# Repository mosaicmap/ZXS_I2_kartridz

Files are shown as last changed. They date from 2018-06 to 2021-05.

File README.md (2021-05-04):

# ZXS_I2_kartridz

Simple ROM cartridge for [Sinclair ZX Interface 2](https://en.wikipedia.org/wiki/ZX_Interface_2).

**This is basically updated Droy's [ZX Cart](http://trastero.speccy.org/cosas/droy/cartuchos/cartuchos_s.htm)**. My version contains an EEPROM chip **W27C512** instead of the 27\*128 or 27\*256. The main reason is that the W27C512 is more common and cheaper than 27\*128 and 27\*256 chips nowadays (Search for W27C512 on eBay...) W27C512 has also a bigger capacity. One cartridge can hold up to four 16 KiB ROM banks. Of course, only one ROM file can be active at one time.  

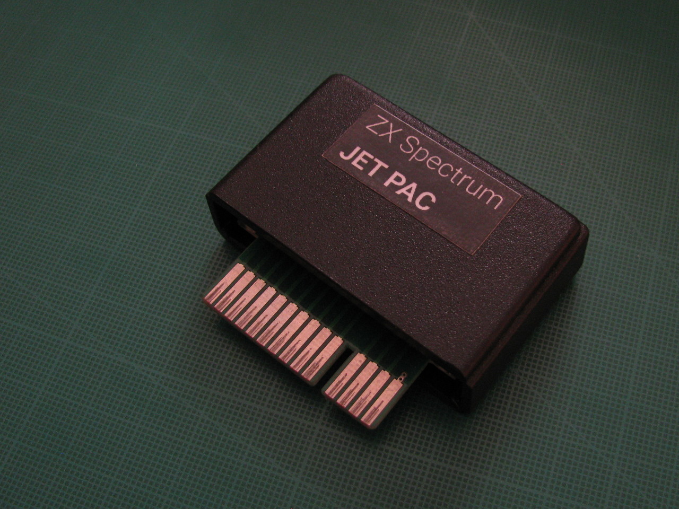
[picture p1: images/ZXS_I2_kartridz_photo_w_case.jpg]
photo_with_case


## Notes 

A HW programmer is required for uploading the ROM file to the EEPROM chip. For example, a relatively cheap universal programmer *MiniPro TL866CS* or *MiniPro TL866 II* from eBay is sufficient. Another option may be a homemade EEPROM programmer made of an Arduino; check for example [eeprom_programmer by StormTrooper](https://github.com/StormTrooper/eeprom_programmer) and similar projects.

To simplify ROMs upload it is possible concat four ROM files to a single file. Command under Linux/Unix: ``cat 1.rom 2.rom 3.rom 4.rom > myCompilation.rom``; under Windows/MS-DOS: ``copy /b 1.rom + 2.rom + 3.rom + 4.rom myCompilation.rom``

Jumpers A14 and A15 decide which 16 KiB ROM bank is active. (A14 and A15 are address pins of the W27C512, not A14 and A15 of the ZX Spectrum Edge connector)

This is only a simple ROM cartridge for 16 KiB ROMs. If you want a better cartridge, check for example sophisticated [Paul Farrow's ZXC4 cartridge](http://www.fruitcake.plus.com/Sinclair/Interface2/Cartridges/Interface2_RC_ZXC4.htm)

## EAGLE project

The project contains: schematic ``ZXS_I2_kartridz.sch`` and board ``ZXS_I2_kartridz.brd``. Also ``lbr/zxs_i2_rom_edge_connector.lbr`` is required.

It was created with a freeware version of Autodesk EAGLE.

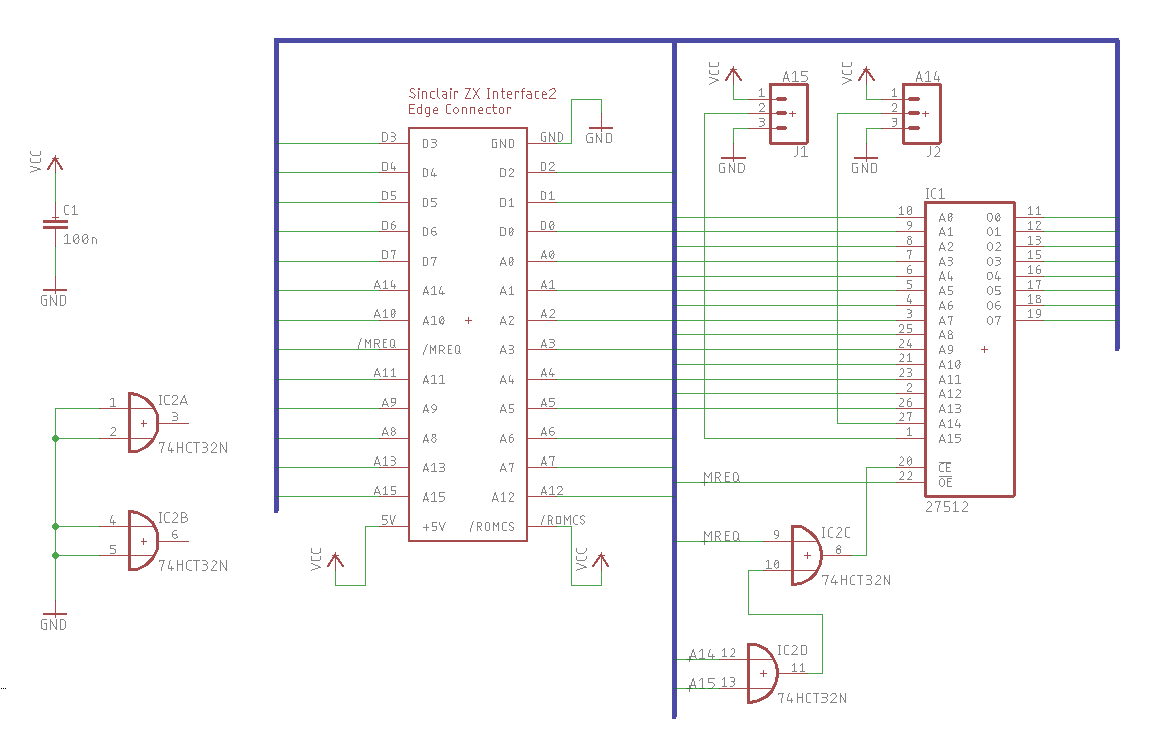
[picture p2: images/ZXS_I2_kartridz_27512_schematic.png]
screenshot-schematic


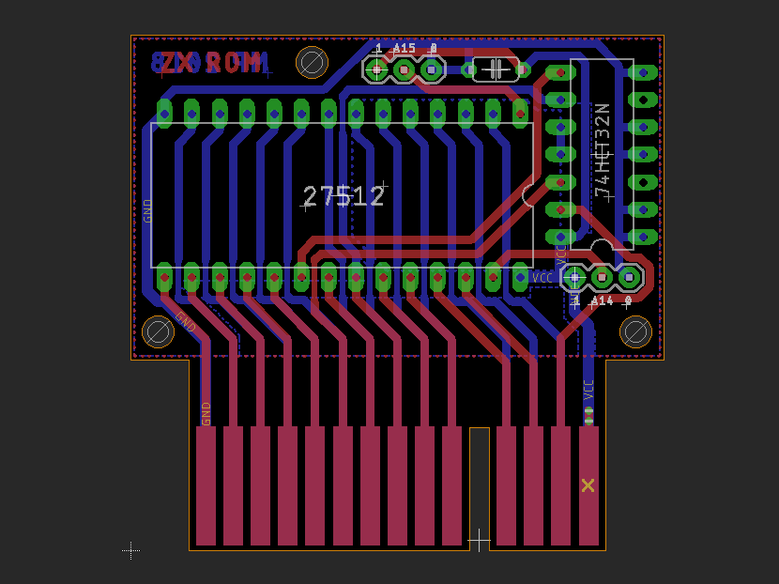
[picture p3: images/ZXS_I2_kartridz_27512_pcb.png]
screenshot-pcb


## ROMs

See nice [overview by Paul Farrow](http://www.fruitcake.plus.com/Sinclair/Interface2/Cartridges/Interface2_RC_Cartridges.htm)

### Officialy released games (1984)

Originaly was released only 10 games. Namely:

- Backgammon
- Cookie
- Chess
- Horace and the Spiders
- Hungry Horace
- Jetpac
- Planetoids
- PSSST
- Space Raiders
- Tranz Am

You can download all ROM files of these games as [archive carts.zip](http://trastero.speccy.org/cosas/droy/cartuchos/carts.zip)

### Unreleased prototypes (cancelled)

- Popeye
- Q*Bert
- Gyruss
- Star Wars - The Arcade Game
- Return of the Jedi - Death Star Battle
- Loco Motion
- Montezuma's Revenge

### Sinclair BASIC for ZX Spectrum (1982) 

### Alternative BASIC interpreters

- OpenSE BASIC (mirrors: [worldofspectrum](https://worldofspectrum.org/archive/software/utilities/opense-basic-andrew-s-owen), [spectrumcomputing](https://spectrumcomputing.co.uk/entry/27510/ZX-Spectrum/OpenSE_BASIC))
- Gosh Woderful BASIC by Geoff Wearmouth ([mirror](https://8bit.yarek.pl/upgrade/zx.roms/gw03.zip))
- [Busy Soft ROM](https://busy.speccy.cz/tvorba/zxromky.htm)
- [prettybasic](https://github.com/reclaimed/prettybasic)
- ...

### Diagnostics 

Very useful ROMs for testing hardware of the ZX Spectrum.

- [Retroleum Diag ROM](http://blog.retroleum.co.uk/smart.zip) 
- [ZX-Diagnostics ROM by Brendan Alford](https://github.com/brendanalford/zx-diagnostics/releases)

### Experimental games

- DeathStar (8 KiB) (See [on fruitcake.plus.com](http://www.fruitcake.plus.com/Sinclair/Interface2/Cartridges/Interface2_RC_New_3rdParty_DeathStar.htm))

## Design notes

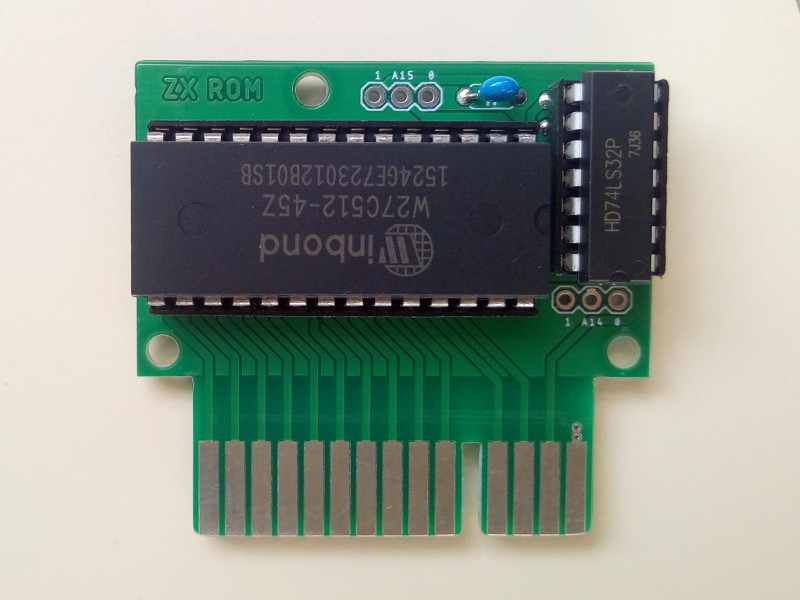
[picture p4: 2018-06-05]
images/ZXS_I2_kartridz_photo_no_jumpers.jpg

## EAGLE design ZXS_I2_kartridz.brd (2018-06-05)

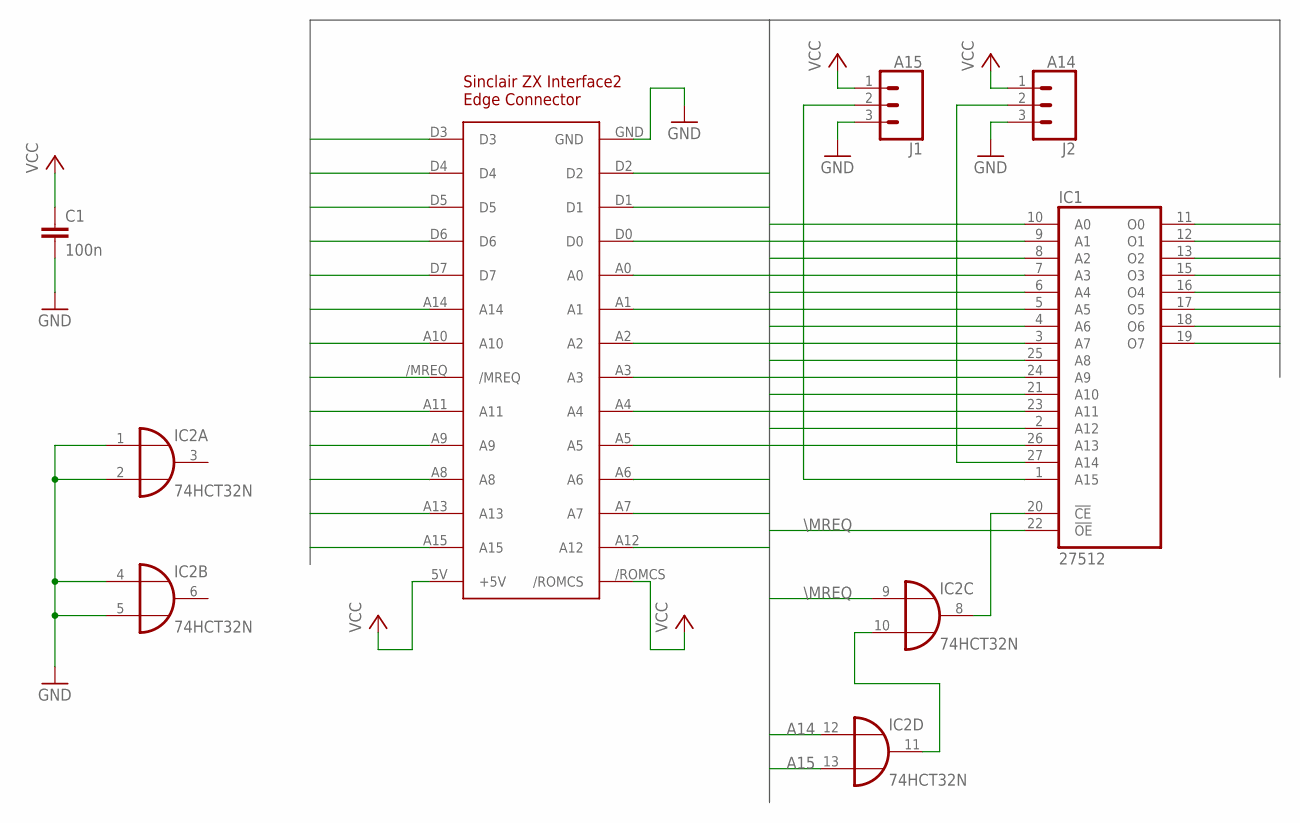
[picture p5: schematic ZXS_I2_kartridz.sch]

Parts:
C1: 100n; C050-024X044
IC1: 27512; DIL28
IC2: 74HCT32N; DIL14
J1: A15; 1X03
J2: A14; 1X03
U$1: ZX_I2_ROM_EDGE_CONNECTOR; ZX_I2_ROM_EDGE_CONNECTOR_V2

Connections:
A0: IC1.10 (A0), U$1.A0
A1: IC1.9 (A1), U$1.A1
A2: IC1.8 (A2), U$1.A2
A3: IC1.7 (A3), U$1.A3
A4: IC1.6 (A4), U$1.A4
A5: IC1.5 (A5), U$1.A5
A6: IC1.4 (A6), U$1.A6
A7: IC1.3 (A7), U$1.A7
A8: IC1.25 (A8), U$1.A8
A9: IC1.24 (A9), U$1.A9
A10: IC1.21 (A10), U$1.A10
A11: IC1.23 (A11), U$1.A11
A12: IC1.2 (A12), U$1.A12
A13: IC1.26 (A13), U$1.A13
A14: IC2.12 (I0), U$1.A14
A15: IC2.13 (I1), U$1.A15
D0: IC1.11 (O0), U$1.D0
D1: IC1.12 (O1), U$1.D1
D2: IC1.13 (O2), U$1.D2
D3: IC1.15 (O3), U$1.D3
D4: IC1.16 (O4), U$1.D4
D5: IC1.17 (O5), U$1.D5
D6: IC1.18 (O6), U$1.D6
D7: IC1.19 (O7), U$1.D7
GND: C1.2, IC1.14 (GND), IC2.1 (I0), IC2.2 (I1), IC2.4 (I0), IC2.5 (I1), IC2.7 (GND), J1.3, J2.3, U$1.GND
unnamed: IC2.10 (I1), IC2.11 (O)
unnamed: IC1.27 (A14), J2.2
unnamed: IC1.20 (!CE), IC2.8 (O)
unnamed: IC1.1 (A15), J1.2
VCC: C1.1, IC1.28 (VCC), IC2.14 (VCC), J1.1, J2.1, U$1.5V (+5V), U$1./ROMCS
\MREQ: IC1.22 (!OE), IC2.9 (I0), U$1./MREQ

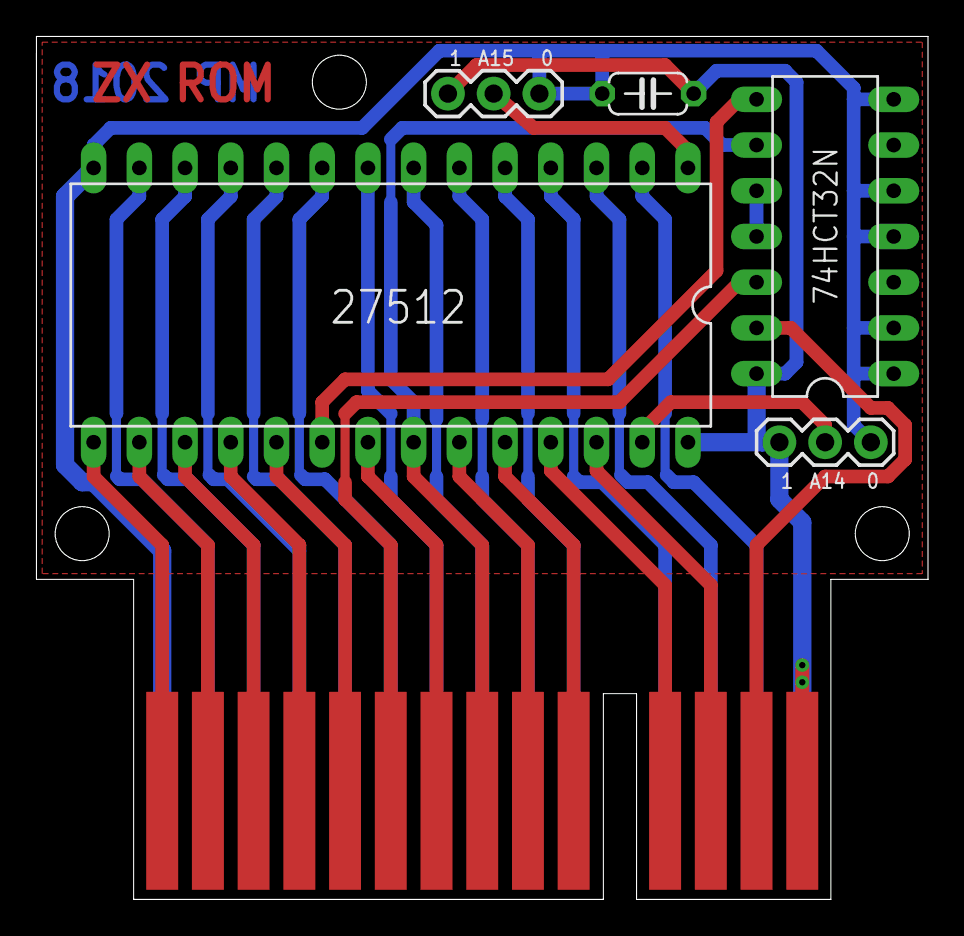
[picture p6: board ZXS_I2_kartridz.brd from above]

Board: 2 copper layers, 49.5 x 47.9 mm, 6 parts (0 on the bottom side), 31 nets.

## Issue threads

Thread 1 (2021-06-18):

Type of enclosure

msolajic, 2021-06-18:
Hi, can you please write which type of enclosure did you use for the cartridge?

mosaicmap, 2021-09-07:
Oh, sorry. I noticed your question right now.
I used a universal project box enclosure from my local electrical components store, specifically: https://www.gme.cz/krabicka-plastova-kp50a-z-71-abs -- KP50A which I cut in half, so I got two enclosures from one box.
It's not as original, of course :)

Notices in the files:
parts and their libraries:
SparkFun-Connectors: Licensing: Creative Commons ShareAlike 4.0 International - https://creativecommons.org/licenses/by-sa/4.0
